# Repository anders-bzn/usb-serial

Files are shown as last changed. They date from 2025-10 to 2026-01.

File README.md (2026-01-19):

# USB to RS232 serial converter
This is a galvanically isolated USB to RS2332 serial adapter. The repository includes project files for both a PCB and an enclosure.

## Short data:
- One USB-C connector and one DB25 D-SUB male connector
- Full ±12V voltage swing on the RS232 side
- Rx/Tx and RTS and CTS signals are available
- Galvanic isolation provided by the MAX22246
- USB to serial conversion handled by the CP2102
- Supported data formats:
    - Data bits: 5, 6, 7, and 8
    - Stop bits: 1, 1.5, and 2
    - Parity: Odd, even, mark, space and none
    - Baud rates from 300 to 921600
- Supports serial break

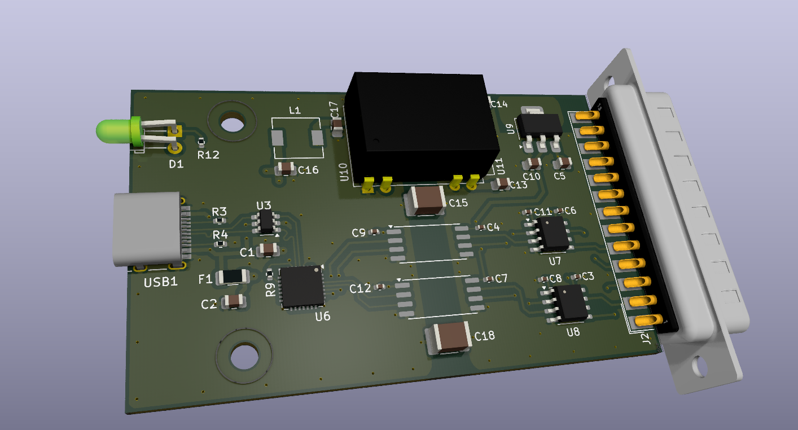
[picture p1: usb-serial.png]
USB serial adapter


## Tools used
This project was created using:
- [KiCad 9.0](https://www.kicad.org/) and [kicad-jlcpcb-tools](https://github.com/Bouni/kicad-jlcpcb-tools) plugin for generating PCB and fabrication files
- [FreeCAD 1.0.2](https://www.freecad.org/downloads.php?lang=en) for 3D modeling the enclosure

## Assembly Instructions
To ensure easy and successful assembly, follow these steps:

1. Mount all surface-mount components.
All necessary files are included for ordering fully assembled PCBs (apart from through hole components) from JLCPCB.
2.  Mount all through-hole components.
This includes the 3mm green LED and the DC/DC converter.
3. Mount the D-SUB connector:
    * Place the PCB into the enclosure so the USB connector and LED aligned correctly.
    * Position the D-SUB connector and screw it in place using the #4-40 standoffs and solder it in place.
    * Disassemble the PCB and solder the other side of the D-SUB connector.
4. Final assembly
    * Reassemble the PCB in the enclosure.
    * Slide on the lid.
    * Secure the lid using 2 × M2.5 × 14mm countersunk machine screws.

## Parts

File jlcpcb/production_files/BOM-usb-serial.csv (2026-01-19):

Comment | Designator | Footprint | LCSC | Quantity
100n | C11,C12,C3,C4,C6,C7,C8,C9 | C_0402_1005Metric | C307331 | 8
10k | R1 | R_0402_1005Metric | C60490 | 1
10u | C10,C16,C17,C2,C5 | C_0805_2012Metric | C15850 | 5
1k5 | R12 | R_0402_1005Metric | C114759 | 1
1u | C1,C13,C14 | C_0805_2012Metric | C28323 | 3
2.2uH | L1 | L_6.3x6.3_H3 | C2849520 | 1
220pF/3kV Y | C15,C18 | C_1812_4532Metric | C2940747 | 2
4k7 | R9 | R_0402_1005Metric | C105870 | 1
5k1 | R3,R4 | R_0402_1005Metric | C105872 | 2
HRO-TYPE-C-31-M-12 | USB1 | USB_C_Receptacle_HRO_TYPE-C-31-M-12 | C165948 | 1
Interface_USB_CP2102N-A01-GQFN28 | U6 | QFN-28-1EP_5x5mm_P0.5mm_EP3.35x3.35mm | C964632 | 1
LM1117DT-5.0 | U9 | SOT-223-3_TabPin2 | C41202 | 1
MAX22246 | U12,U13 | MAX22246 | C7457939 | 2
Polyfuse 1,8A | F1 | Fuse_1206_3216Metric | C70081 | 1
SN75155 | U7,U8 | SO-8_3.9x4.9mm_P1.27mm | C139383 | 2
USBLC6-2SC6 | U3 | SOT-23-6 | C7519 | 1
PEME2-5-D12-D | U11 | Converter_DCDC_CUI_INC_PEME2-xx-Dxx-D |  | 1
LED | D1 | LED_D3.0mm_Horizontal_O3.81mm_Z10.0mm |  | 1
MountingHole | H2 | MountingHole_3.2mm_M3 |  | 1
DB25_Plug | J2 | DSUB-25_Male_EdgeMount_P2.77mm |  | 1
TDR2-1222WI | U10 | Converter_DCDC_TRACO_TDR2-xxxxWI |  | 1
MountingHole | H1 | MountingHole_3.2mm_M3 |  | 1

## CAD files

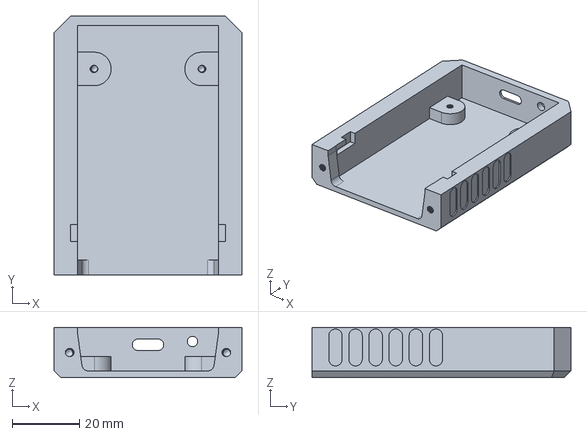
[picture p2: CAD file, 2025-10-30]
mechanics/enclosure.FCStd
56.0 x 77.3 x 15.0 mm

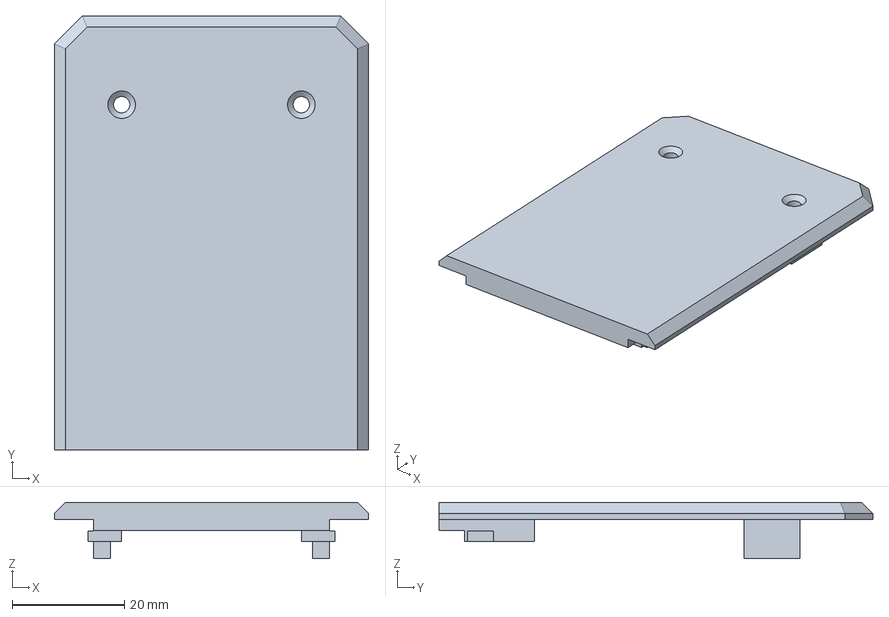
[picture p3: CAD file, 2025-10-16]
mechanics/enclosure-Lid.3mf
56.0 x 77.3 x 10.0 mm

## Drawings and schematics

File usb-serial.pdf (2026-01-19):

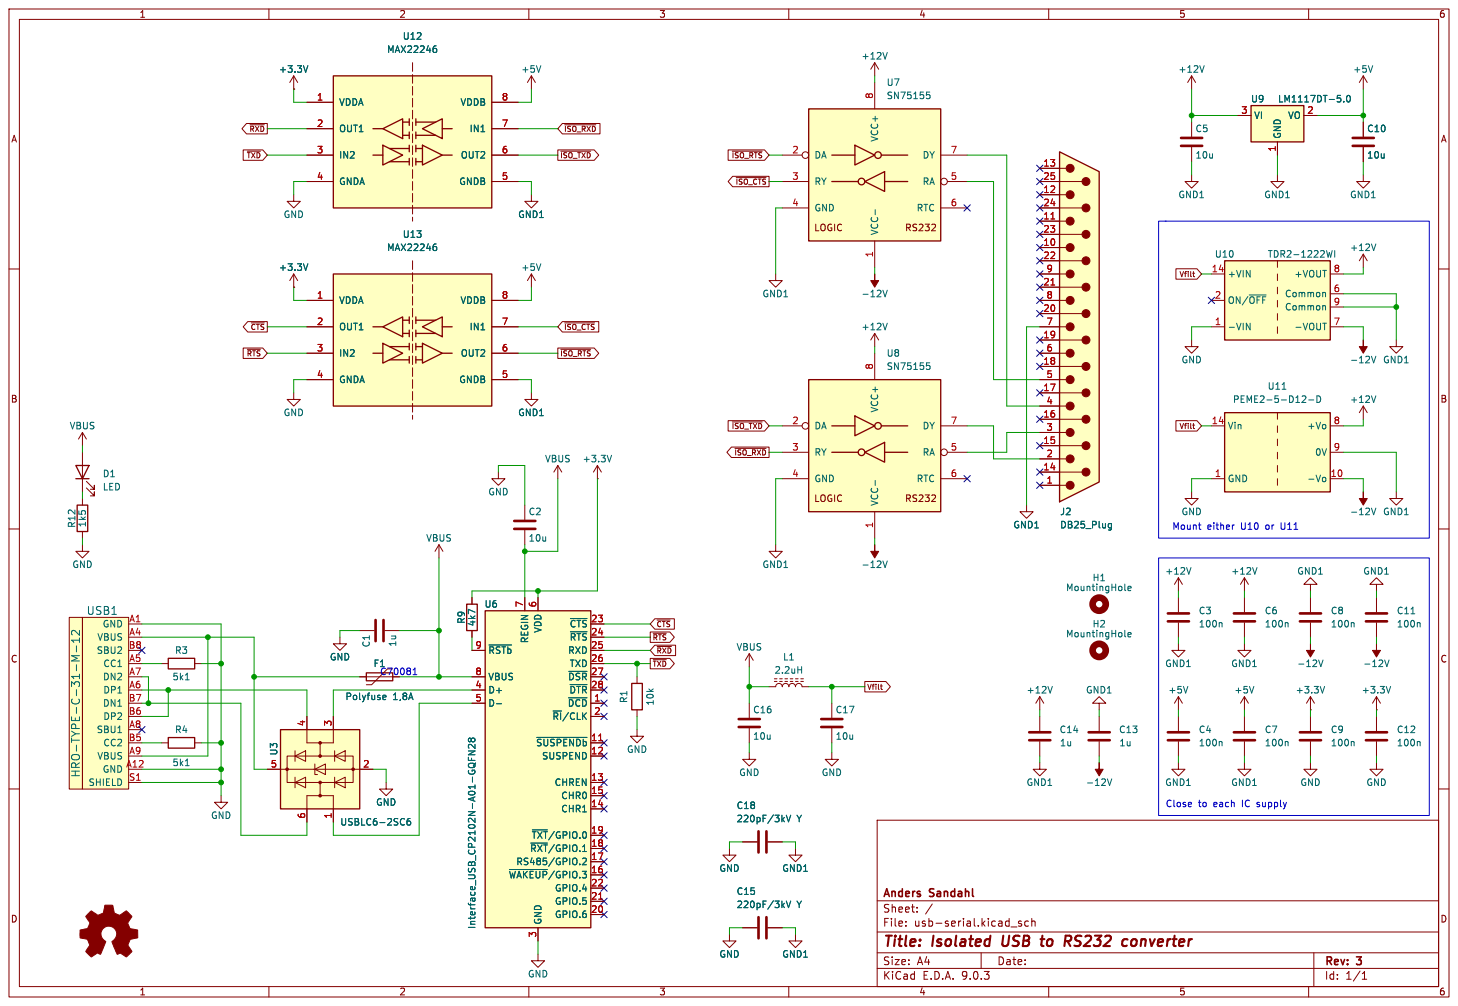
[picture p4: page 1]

8 VCC- 1 DY 7 RA 5 RTC 6 U7SN75155 R4

8 VCC- 1 DY 7 RA 5 RTC 6 U8SN75155 GND

3 U3 USBLC6-2SC6 F1 Polyfuse 1,8A GND R12 1k5 GND A1 VBUS A4 SBU2 B8 CC1 A5 DN2 A7 DP1 A6 DN1 B7 DP2 B6 SBU1 A8 CC2 B5 VBUS A9 GND A12 SHIELD S1 USB1 HRO-TYPE-C-31-M-12

3 ~{CTS} 23 ~{RTS} 24 RXD 25 TXD 26 ~{DSR} 27 ~{DTR} 28 ~{DCD}1 ~{RI}/CLK2 ~{SUSPENDb}11 SUSPEND 12 CHREN 13 CHR0 15 CHR1 14 ~{TXT}/GPIO.019 ~{RXT}/GPIO.118 RS485/GPIO.2 17 ~{WAKEUP}/GPIO.316 GPIO.4 22 GPIO.5 21 GPIO.6 20 U6 Interface_USB_CP2102N-A01-GQFN28 GND

3 ~{CTS} 23 ~{RTS} 24 RXD 25 TXD 26 ~{DSR} 27 ~{DTR} 28 ~{DCD}1 ~{RI}/CLK2 ~{SUSPENDb}11 SUSPEND 12 CHREN 13 CHR0 15 CHR1 14 ~{TXT}/GPIO.019 ~{RXT}/GPIO.118 RS485/GPIO.2 17 ~{WAKEUP}/GPIO.316 GPIO.4 22 GPIO.5 21 GPIO.6 20 GND GND1 C18

Id: 1/1 Title: Isolated USB to RS232 converter File: usb-serial.kicad_sch Sheet: / Anders Sandahl

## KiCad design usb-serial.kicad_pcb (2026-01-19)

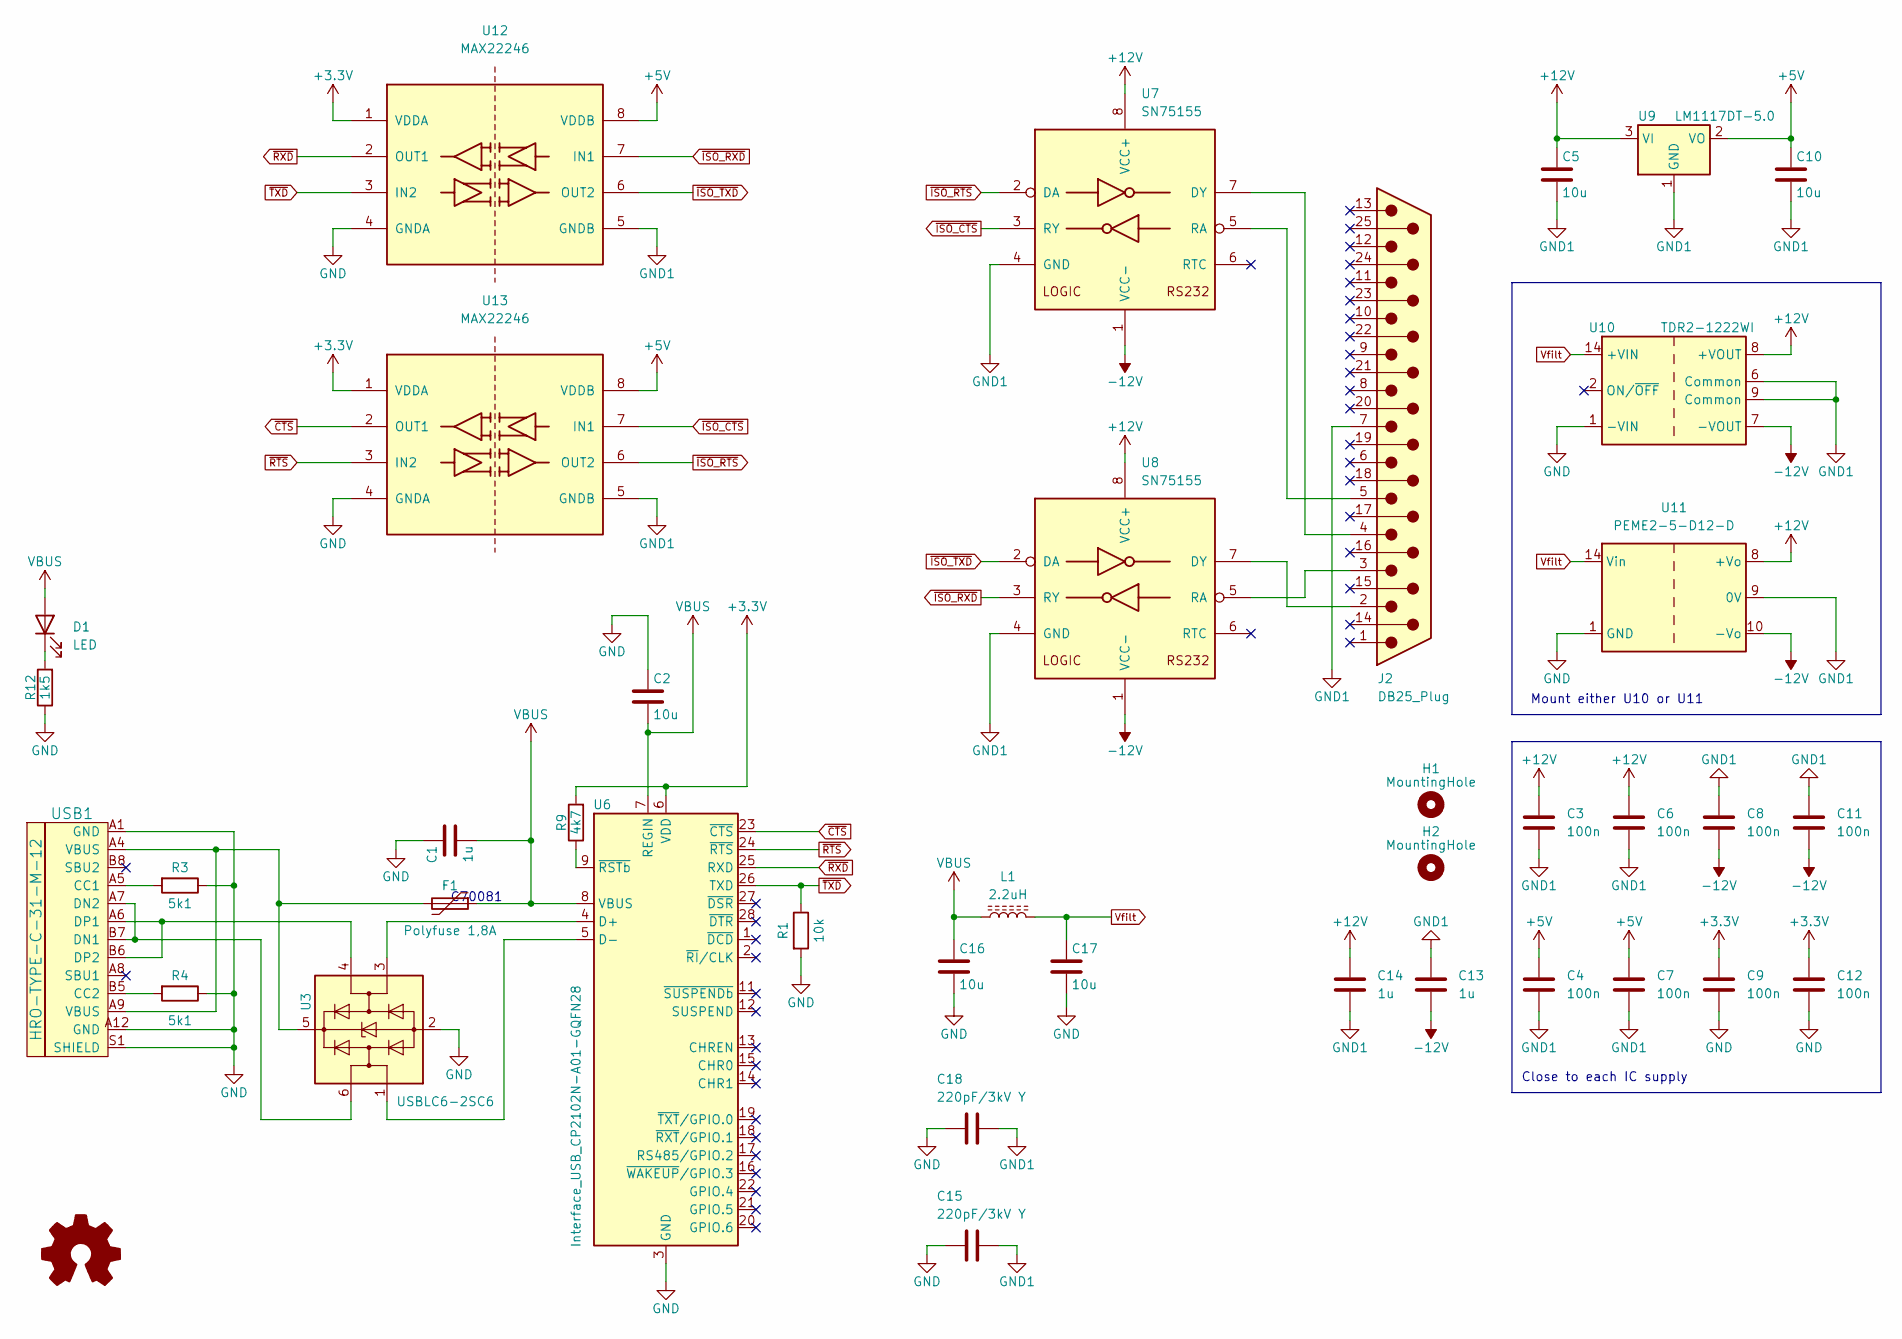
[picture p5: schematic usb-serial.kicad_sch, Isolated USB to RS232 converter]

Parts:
C1, C13, C14: 1u; C_0805_2012Metric
C2, C5, C10, C16, C17: 10u; C_0805_2012Metric
C3, C4, C6, C7, C8, C9, C11, C12: 100n; C_0402_1005Metric
C15, C18: 220pF/3kV Y; C_1812_4532Metric
D1: LED; LED_D3.0mm_Horizontal_O3.81mm_Z10.0mm
F1: Polyfuse 1,8A; Fuse_1206_3216Metric
H1, H2: MountingHole; MountingHole_3.2mm_M3
J2: DB25_Plug; DSUB-25_Male_EdgeMount_P2.77mm
L1: 2.2uH; L_6.3x6.3_H3
R1: 10k; R_0402_1005Metric
R3, R4: 5k1; R_0402_1005Metric
R9: 4k7; R_0402_1005Metric
R12: 1k5; R_0402_1005Metric
U3: USBLC6-2SC6; SOT-23-6
U6: Interface_USB_CP2102N-A01-GQFN28; QFN-28-1EP_5x5mm_P0.5mm_EP3.35x3.35mm
U7, U8: SN75155; SO-8_3.9x4.9mm_P1.27mm
U9: LM1117DT-5.0; SOT-223-3_TabPin2
U10: TDR2-1222WI; Converter_DCDC_TRACO_TDR2-xxxxWI
U11: PEME2-5-D12-D; Converter_DCDC_CUI_INC_PEME2-xx-Dxx-D
U12, U13: MAX22246
USB1: HRO-TYPE-C-31-M-12; USB_C_Receptacle_HRO_TYPE-C-31-M-12

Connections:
+3.3V: C9.1, C12.1, R9.2, U6.6 (VDD), U12.1 (VDDA), U13.1 (VDDA)
+5V: C4.1, C7.1, C10.1, U9.2 (VO), U12.8 (VDDB), U13.8 (VDDB)
+12V: C3.1, C5.1, C6.1, C14.2, U7.8 (VCC+), U8.8 (VCC+), U9.3 (VI), U10.8 (+VOUT), U11.8 (+Vo)
-12V: C8.2, C11.2, C13.1, U7.1 (VCC-), U8.1 (VCC-), U10.7 (-VOUT), U11.10 (-Vo)
GND: C1.1, C2.1, C9.2, C12.2, C15.2, C16.2, C17.2, C18.2, R1.2, R3.1, R4.1, R12.1, U3.2 (GND), U6.3 (GND), U6.29 (GND), U10.1 (-VIN), U11.1 (GND), U12.4 (GNDA), U13.4 (GNDA), USB1.A1 (GND), USB1.A12 (GND), USB1.S1 (SHIELD)
GND1: C3.2, C4.2, C5.2, C6.2, C7.2, C8.1, C10.2, C11.1, C13.2, C14.1, C15.1, C18.1, J2.7, U7.4 (GND), U8.4 (GND), U9.1 (GND), U10.6 (Common), U10.9 (Common), U11.9 (0V), U12.5 (GNDB), U13.5 (GNDB)
unnamed: D1.1 (K), R12.2
unnamed: F1.2, U3.5 (VBUS), USB1.A4 (VBUS), USB1.A9 (VBUS)
unnamed: U3.3 (I/O2), U6.4 (D+)
unnamed: U3.1 (I/O1), U6.5 (D-)
unnamed: R9.1, U6.9 (~RSTb)
unnamed: J2.4, U7.7 (DY)
unnamed: J2.5, U7.5 (RA)
unnamed: J2.2, U8.7 (DY)
unnamed: J2.3, U8.5 (RA)
unnamed: R3.2, USB1.A5 (CC1)
unnamed: R4.2, USB1.B5 (CC2)
unnamed: U3.6 (I/O1), USB1.A7 (DN2), USB1.B7 (DN1)
unnamed: U3.4 (I/O2), USB1.A6 (DP1), USB1.B6 (DP2)
VBUS: C1.2, C2.2, C16.1, D1.2 (A), F1.1, L1.1, U6.7 (REGIN), U6.8 (VBUS)
Vfilt: C17.1, L1.2, U10.14 (+VIN), U11.14 (Vin)
~CTS: U6.23 (~CTS), U13.2 (OUT1)
~ISO_CTS: U7.3 (RY), U13.7 (IN1)
~ISO_RTS: U7.2 (DA), U13.6 (OUT2)
~ISO_RXD: U8.3 (RY), U12.7 (IN1)
~ISO_TXD: U8.2 (DA), U12.6 (OUT2)
~RTS: U6.24 (~RTS), U13.3 (IN2)
~RXD: U6.25 (RXD), U12.2 (OUT1)
~TXD: R1.1, U6.26 (TXD), U12.3 (IN2)

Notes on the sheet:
Close to each IC supply
C70081
Mount either U10 or U11

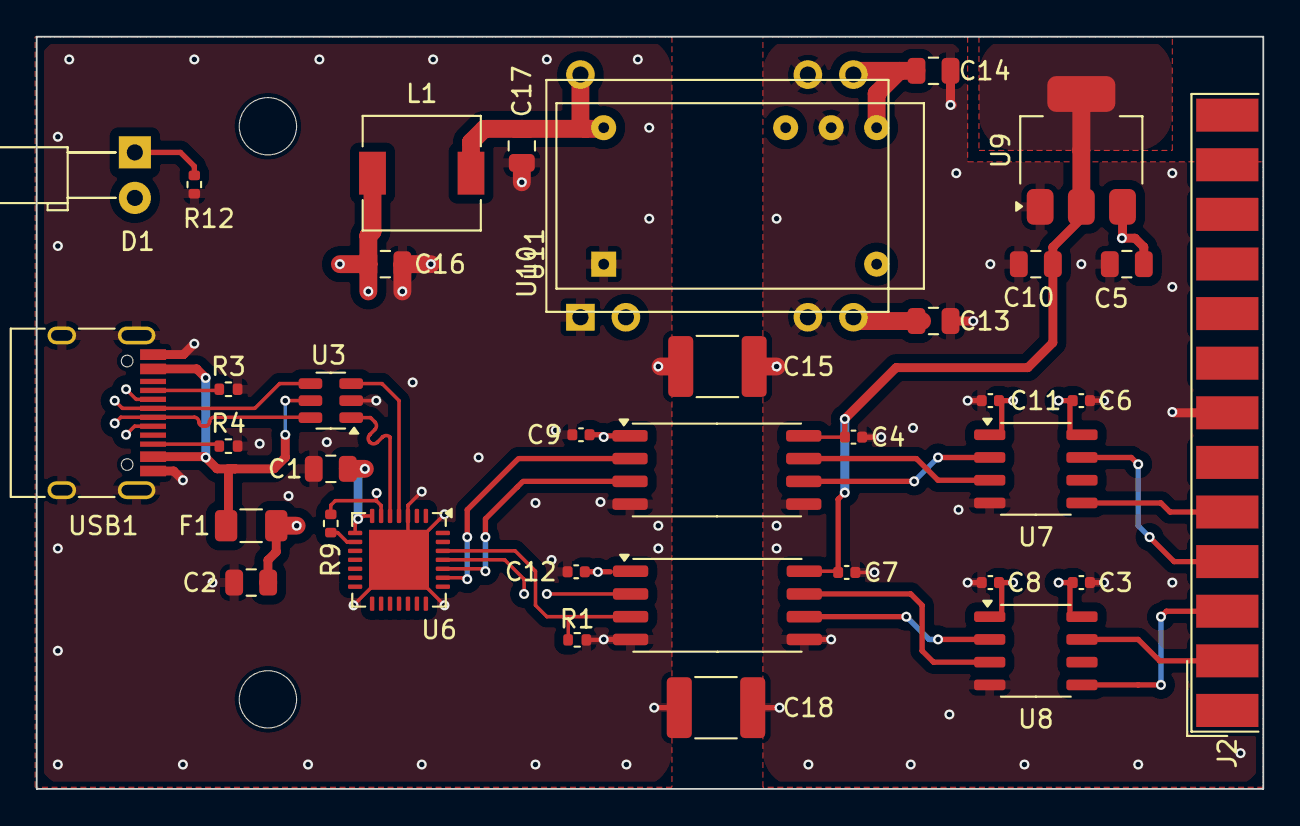
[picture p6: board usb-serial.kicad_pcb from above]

Board: 4 copper layers, 68.5 x 42.0 mm, 39 parts (0 on the bottom side), 29 nets.

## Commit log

2024-03-07 Add fabrication fies
    [BOM-usb-serial.csv, usb-serial.kicad_pcb, usb-serial.kicad_sch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]
2024-04-03 EMC filter according to DC/DC datasheet
    [usb-serial.kicad_pcb, usb-serial.kicad_sch]
2024-04-03 Print drawing sheet on pdf
2025-10-07 mechanics: Add 3D model
    [closure-Bottom.3mf, closure-Lid.3mf, closure.FCStd]
2025-10-07 usb-serial: Change opto to MAX 22246 isolator.
    [usb-serial.kicad_pcb, usb-serial.kicad_sch]
2025-10-07 jlcpcb: Updated production files
    Updated production files to reflect the updated schematics and PCB.
    [BOM-usb-serial.csv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]
2025-10-08 Updated 3D image of PCB
    [usb-serial.kicad_pcb]
2025-10-08 REAdME.md: Update
    - Added short data on the converter
    - Added assembly instructions
    - Added used tools
2025-10-16 usb-serial: Fix swapped RXD and TXD
    [BOM-usb-serial.csv, usb-serial.kicad_pcb, usb-serial.kicad_sch]
2025-10-16 mechanics: Adjusted countersink size
    [closure-Lid.3mf, closure.FCStd, enclosure-Bottom.3mf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]
2025-10-30 mechanics: Add threads to model
    Model threads.
    - #4-40 to the DSUB stand offs
    - M2.5 to the screws that holds the lid
    [enclosure-Bottom.3mf, enclosure.FCStd]
2025-11-03 Re-generate production files
    [BOM-usb-serial.csv, usb-serial.kicad_pcb]
2026-01-19 Add resistor to fix serial break support
    There must be pulldown resistor of 10k from TxD to GND on the CP2102 to
    make serial break to work.
    Also, updated to use KiCad 9.0 as PCB design tool.
    [BOM-usb-serial.csv, usb-serial.kicad_pcb, usb-serial.kicad_sch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]
